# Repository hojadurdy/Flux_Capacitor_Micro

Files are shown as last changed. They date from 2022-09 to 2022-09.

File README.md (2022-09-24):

# Flux Capacitor Micro

### WHAT IS IT?

A tiny (36mm x 29mm) pin badge and keychain PCB version of Flux Capacitor featuring 25 animated LEDs that animate to create the “fluxxing” effect. It’s 100% decorative, it doesn’t actually let you travel through time when worn around the neck.

FLUXXXXING

This tiny Flux Capacitor is controlled by a Microchip ATtiny1616 microcontroller. Thankfully this board has a much lower power requirement than the silkscreen indicates on the back, and skips along, sipping power from the single CR2016/LIR2016 coin cell battery (instead of plutonium or a lightning strike), slipped into the rear mounted coin cell holder. By using PWM (Pulse Width Modulation) pins for 8 channels of 3 paralleled LEDs, different animation patterns are generated for the fluxxxing effect. In settings mode, users are able change between 8 different animation, speed and LED brightness.

### WHAT IS NEW WITH THIS DESIGN?

- Main difference is the new design significantly slimmer due to slim battery holder and changing PCB thickness from 1.6mm to 0.8mm. Older design (V3) had a thickness of 6.15mm, the new design is only 3.4mm thick. 
- Front design has been updated to look like similar to Flux Capacitor Mini design. 
- A much brighter center LED has been added to get a brighter center beam flash, similar to the original Flux Capacitor.
- Instead of just 2 animations, now there are 8 different animations that can be selected in settings.
- Power toggle switch has been replaced with a push button. When pressed device goes in do "Power Down" mode. during "Power Down" mode device only consumes 0.5 uA.

Below you can see the thickness comparison of V3 on the left and V4 on the right.

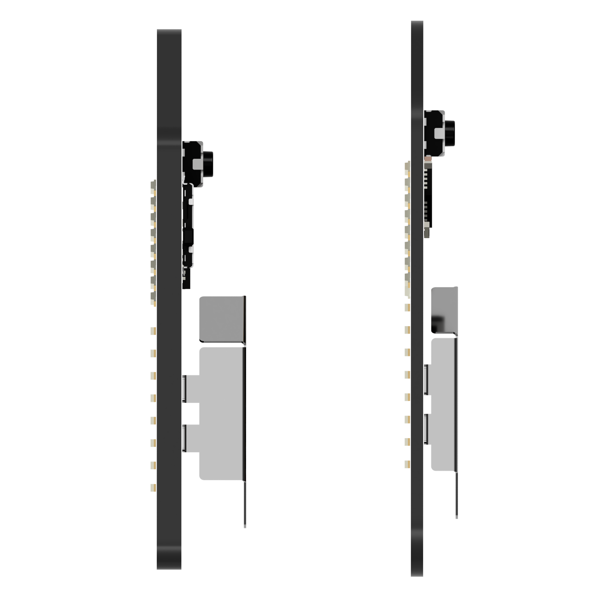
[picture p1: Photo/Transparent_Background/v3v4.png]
V3 vs V4


### HOW LONG WILL THE BATTERY LAST?

CR2016 (Non-Rechargeable) with average of 90 mAh battery capacity.

- 100% LED Brightness :  80 Hours
- 25%  LED Brightness :  128 Hours

LIR2016 (Rechargeable) with average of 20 mAh battery capacity.

- 100% LED Brightness :  18 Hours
- 25%  LED Brightness :  28 Hours

### HOW TO SETUP AND OPERATE

To begin with, turn on the device by pressing power button. In order to enter settings mode just hold the set button for 1 second. If all of the LEDs flashes twice, you are successfully entered settings mode. 

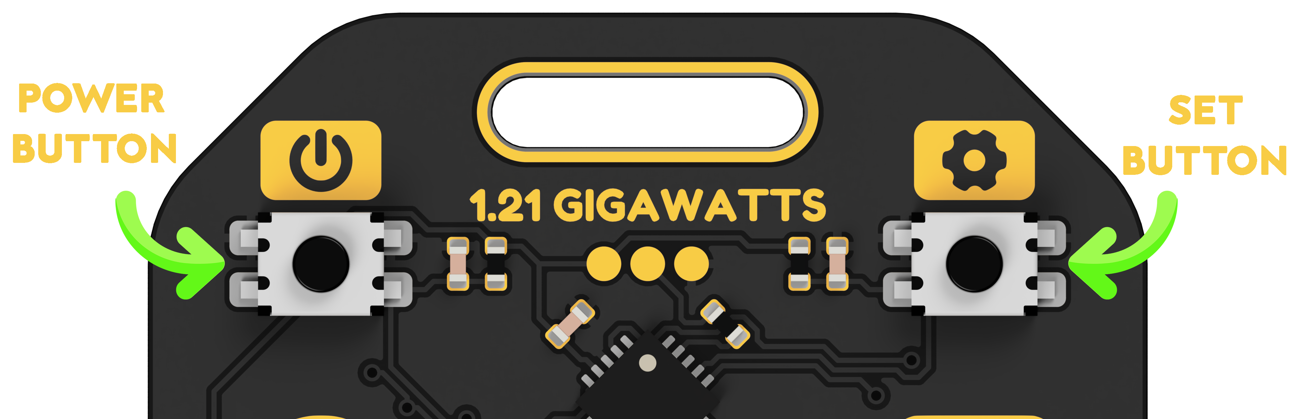
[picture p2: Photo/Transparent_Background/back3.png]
BUTTONS BUTTONS


After the LEDs flash you will see that only single LED remains on. That single LED shows which animation is selected. To change that, just short press the set button and the LED should start shifting from inner to outer LED with each press. After selecting the preferred animation, hold the set button for 1 second to save. LEDs should flash twice to confirm.

Next setting is animation speed. To change the animation speed, just short press the set button to increase the speed. LEDs will turn on from inner to outer to indicate animation speed. At maximum speed all LEDs should be on. Hold the set button for 1 second to save animation speed. LEDs should flash twice to confirm.

Last setting is LED brightness. Same as before to change the brightness just short press the set buttonto increase the brightness. LEDs will turn on from inner to outer to indicate brightness level. At maximum brightness all LEDs should be on. Hold the set button for 1 second to save brightness setting. LEDs should flash twice to confirm and device should exit the setting mode. LEDs should start animating.

**If you short press the button with gear icon during normal operation, device initiates engage mode.
LEDs start to animate faster with much brighter center beam as shown in the video below.**

### P.S.
**Only CR2016 or LIR2016 batteries are compatible. If you prefer to use larger CR2032 or LIR2032 batteries, message me from store page. I will change the battery holder to a larger one. Also batteries are not included due to shipping restrictions.**



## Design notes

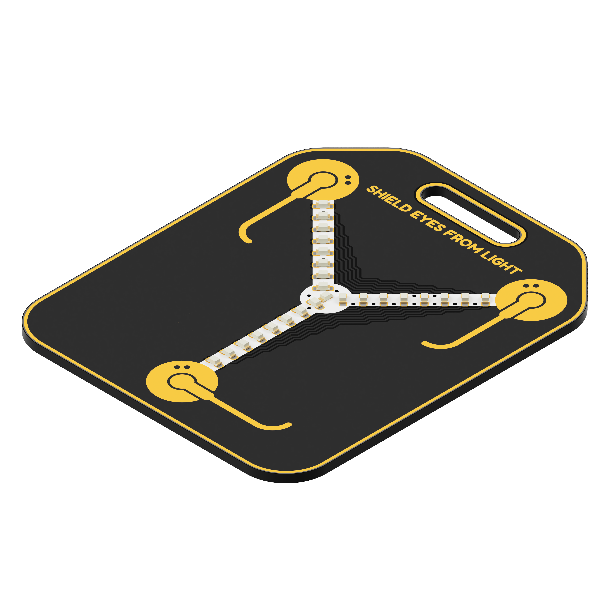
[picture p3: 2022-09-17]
Photo/Transparent_Background/bottom_corner_2.png

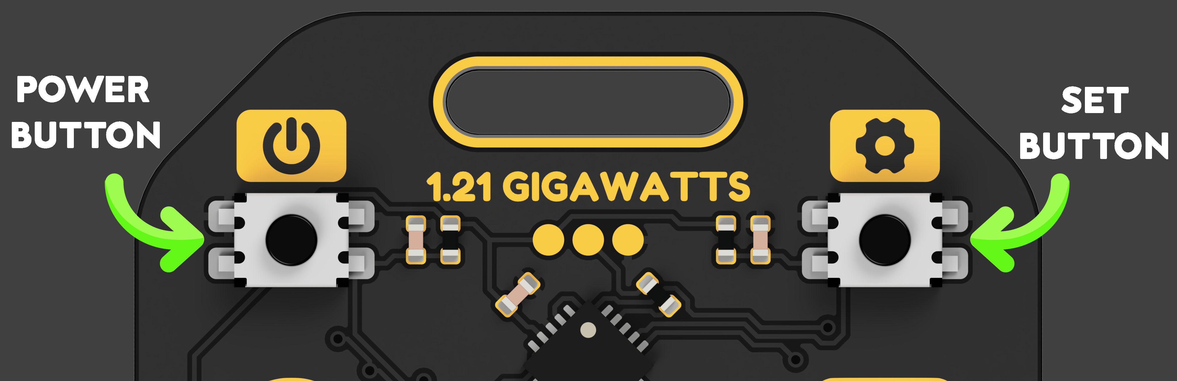
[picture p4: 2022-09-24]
Photo/Transparent_Background/back2.png

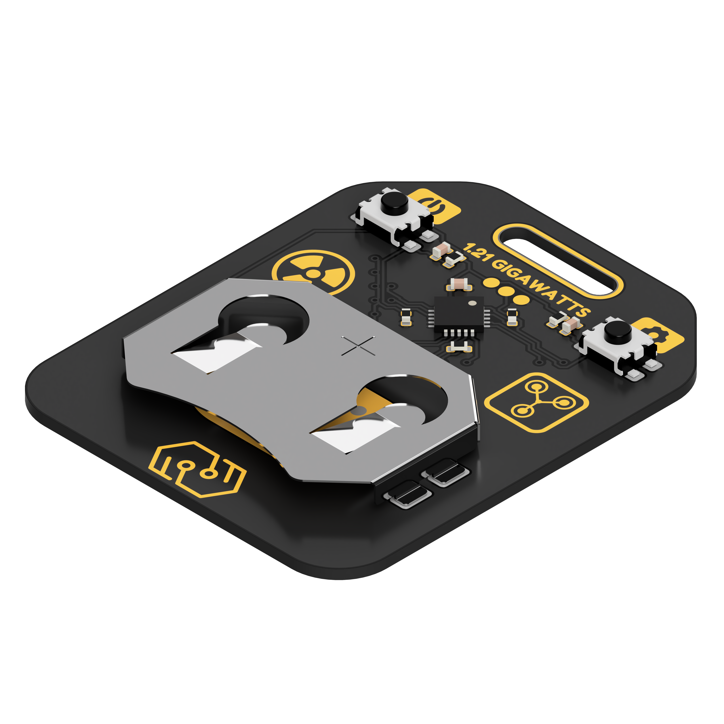
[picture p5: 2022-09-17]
Photo/Transparent_Background/bottom_corner.png

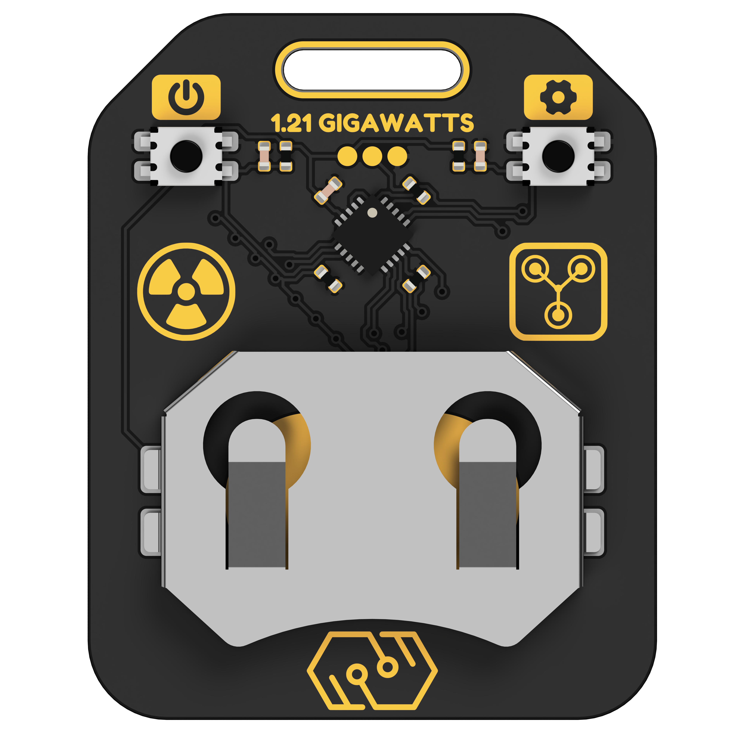
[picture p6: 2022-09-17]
Photo/Transparent_Background/back.png

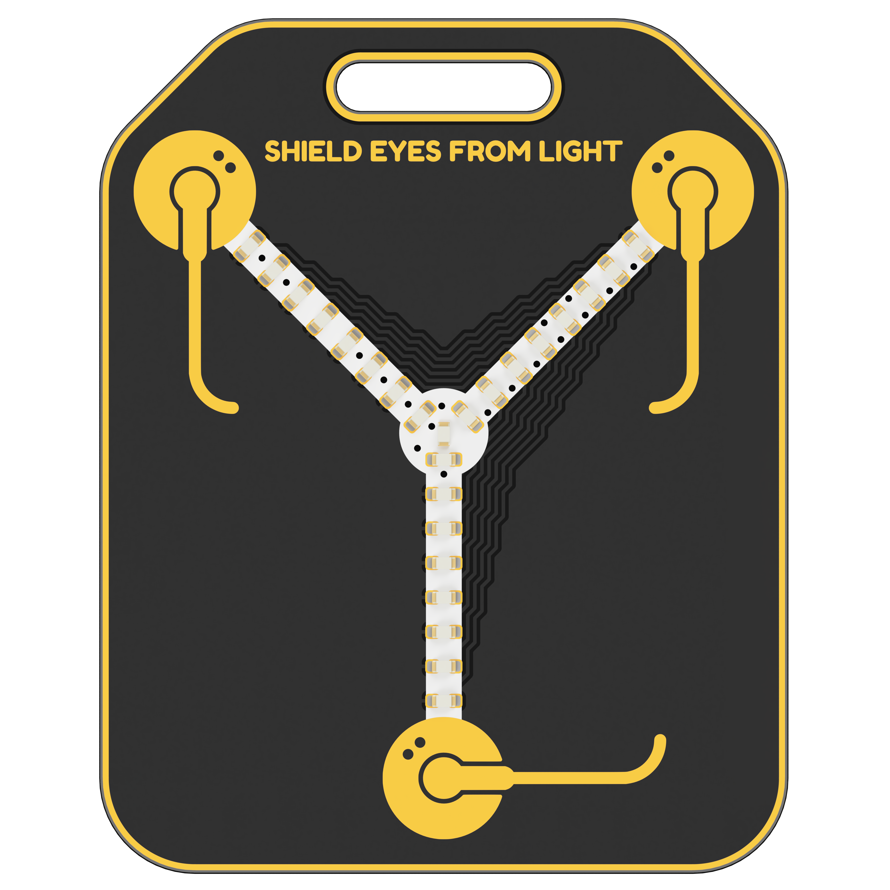
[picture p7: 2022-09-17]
Photo/Transparent_Background/front.png

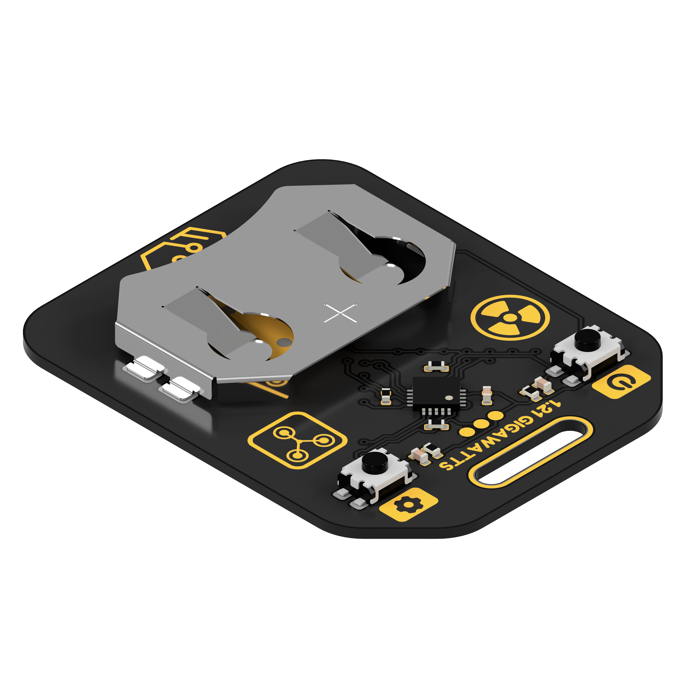
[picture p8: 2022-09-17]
Photo/Transparent_Background/top_corner.png

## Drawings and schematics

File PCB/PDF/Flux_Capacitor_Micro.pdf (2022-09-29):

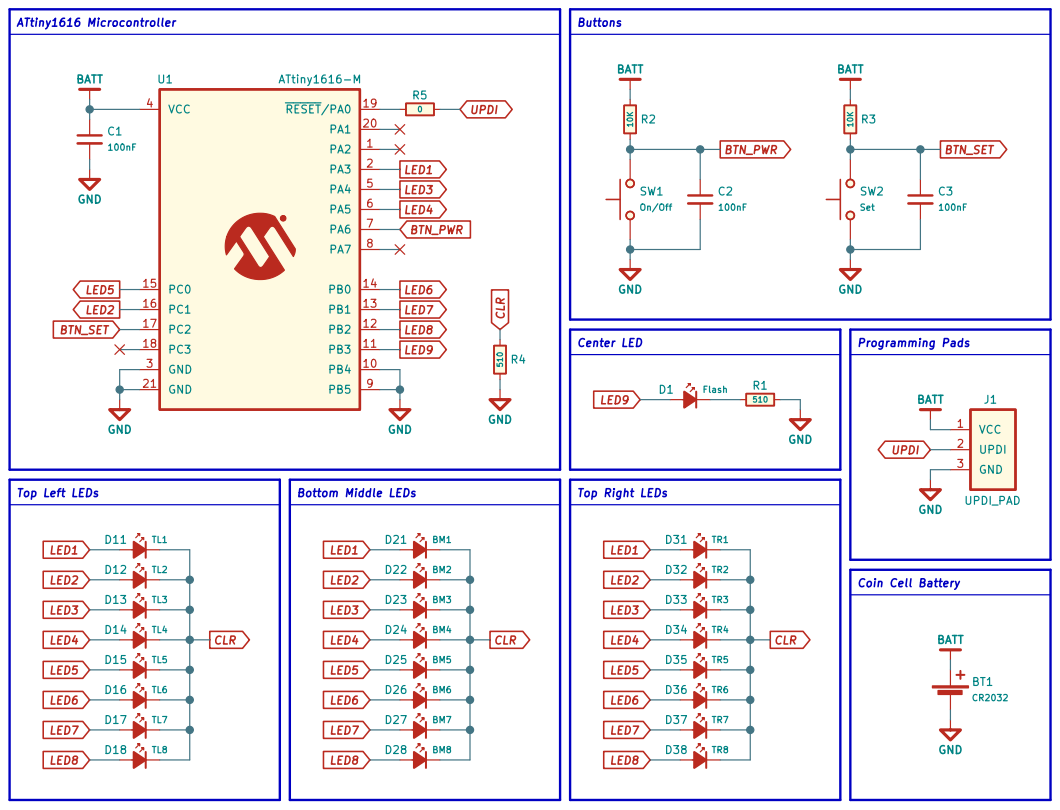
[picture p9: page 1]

Curious Design Labs | Hojadurdy Durdygylyjov

Micro version of Flux Capacitor from the movie Back to the Future

License: CC BY-NC-SA 4.0 Sheet: 1/1

File: Flux_Capacitor_Micro.kicad_sch

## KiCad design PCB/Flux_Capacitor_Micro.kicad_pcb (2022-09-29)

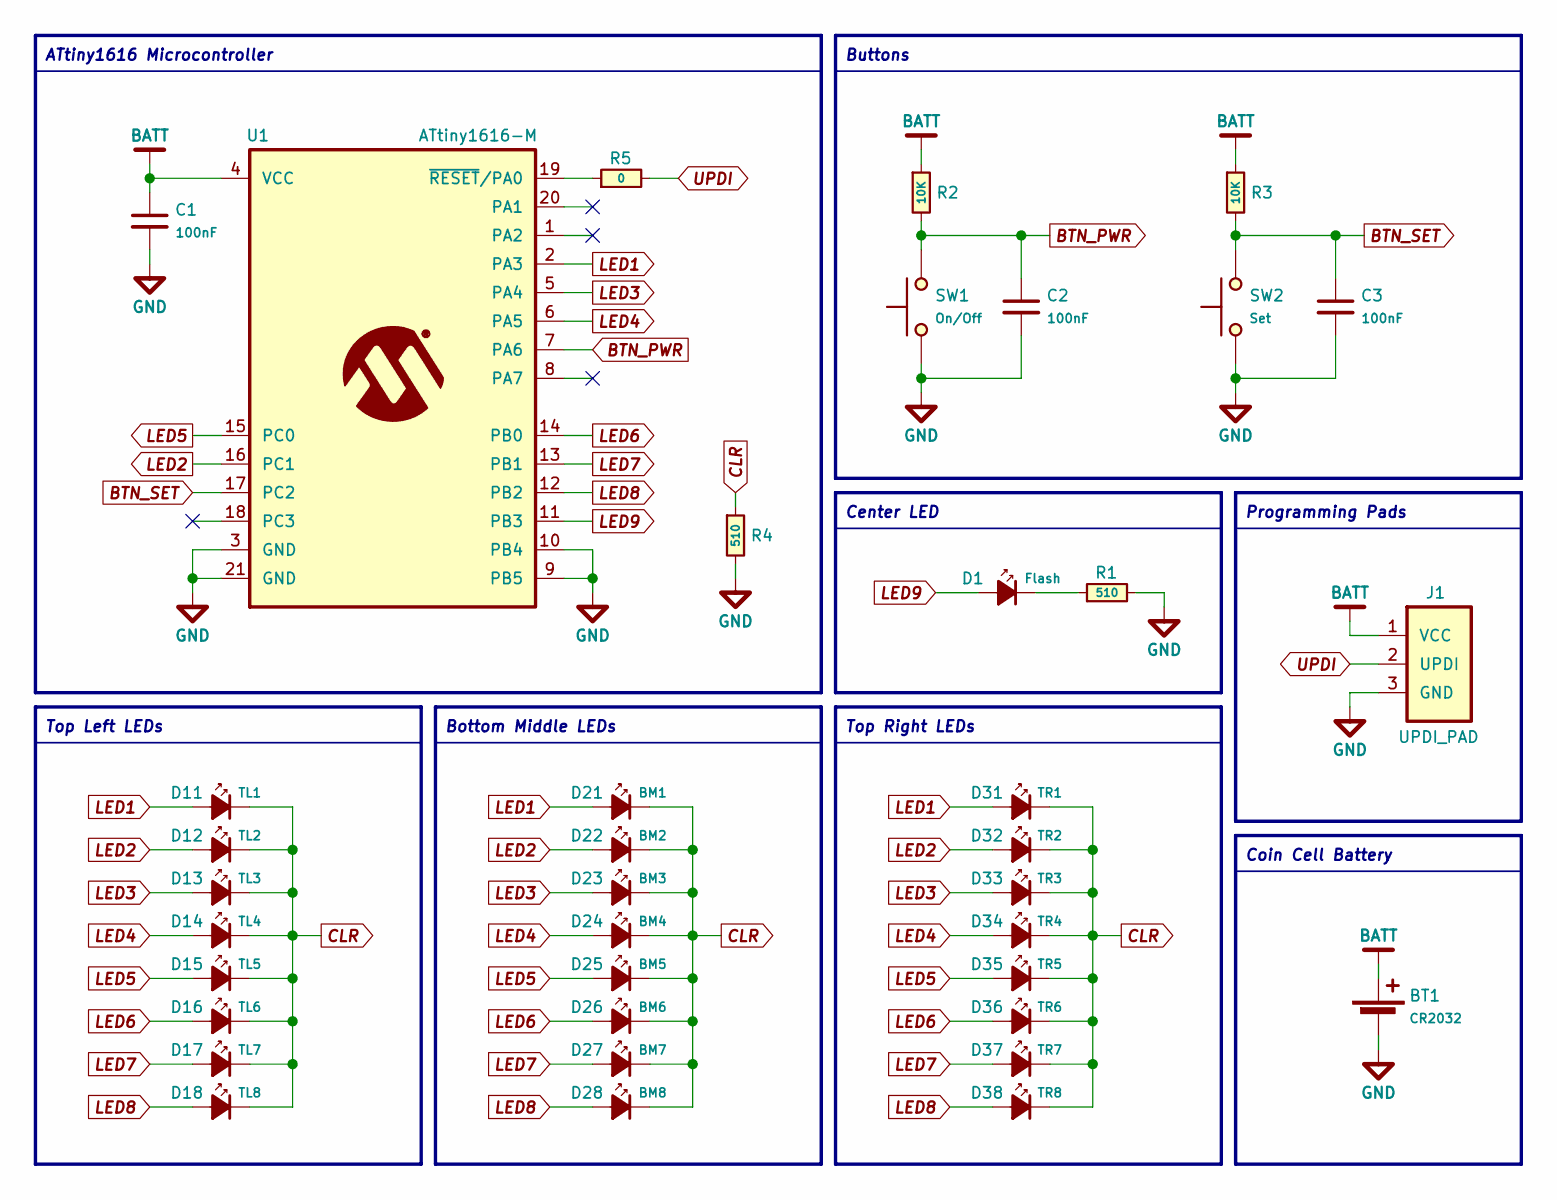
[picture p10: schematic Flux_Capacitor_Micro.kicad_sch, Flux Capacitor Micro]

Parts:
BT1: CR2032; MY-2016-02
C1, C2, C3: 100nF; C_0402_1005Metric
D1: Flash; LED_0402_1005Metric
D11: TL1; LED_0402_1005Metric
D12: TL2; LED_0402_1005Metric
D13: TL3; LED_0402_1005Metric
D14: TL4; LED_0402_1005Metric
D15: TL5; LED_0402_1005Metric
D16: TL6; LED_0402_1005Metric
D17: TL7; LED_0402_1005Metric
D18: TL8; LED_0402_1005Metric
D21: BM1; LED_0402_1005Metric
D22: BM2; LED_0402_1005Metric
D23: BM3; LED_0402_1005Metric
D24: BM4; LED_0402_1005Metric
D25: BM5; LED_0402_1005Metric
D26: BM6; LED_0402_1005Metric
D27: BM7; LED_0402_1005Metric
D28: BM8; LED_0402_1005Metric
D31: TR1; LED_0402_1005Metric
D32: TR2; LED_0402_1005Metric
D33: TR3; LED_0402_1005Metric
D34: TR4; LED_0402_1005Metric
D35: TR5; LED_0402_1005Metric
D36: TR6; LED_0402_1005Metric
D37: TR7; LED_0402_1005Metric
D38: TR8; LED_0402_1005Metric
J1: UPDI_PAD; PogoPad_1x03_P1.27mm
R1, R4: 510; R_0402_1005Metric
R2, R3: 10K; R_0402_1005Metric
R5: 0; R_0402_1005Metric
SW1: On/Off; K2-1809SN-D4DW-06
SW2: Set; K2-1809SN-D4DW-06
U1: ATtiny1616-M; VQFN-20-1EP_3x3mm_P0.4mm_EP1.7x1.7mm

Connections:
BATT: BT1.1 (+), C1.1, J1.1 (VCC), R2.1, R3.1, U1.4 (VCC)
BTN_PWR: C2.1, R2.2, SW1.2, U1.7 (PA6)
BTN_SET: C3.1, R3.2, SW2.2, U1.17 (PC2)
CLR: D11.1 (K), D12.1 (K), D13.1 (K), D14.1 (K), D15.1 (K), D16.1 (K), D17.1 (K), D18.1 (K), D21.1 (K), D22.1 (K), D23.1 (K), D24.1 (K), D25.1 (K), D26.1 (K), D27.1 (K), D28.1 (K), D31.1 (K), D32.1 (K), D33.1 (K), D34.1 (K), D35.1 (K), D36.1 (K), D37.1 (K), D38.1 (K), R4.1
GND: BT1.2 (-), C1.2, C2.2, C3.2, J1.3 (GND), R1.2, R4.2, SW1.1, SW2.1, U1.3 (GND), U1.9 (PB5), U1.10 (PB4), U1.21 (GND)
LED1: D11.2 (A), D21.2 (A), D31.2 (A), U1.2 (PA3)
LED2: D12.2 (A), D22.2 (A), D32.2 (A), U1.16 (PC1)
LED3: D13.2 (A), D23.2 (A), D33.2 (A), U1.5 (PA4)
LED4: D14.2 (A), D24.2 (A), D34.2 (A), U1.6 (PA5)
LED5: D15.2 (A), D25.2 (A), D35.2 (A), U1.15 (PC0)
LED6: D16.2 (A), D26.2 (A), D36.2 (A), U1.14 (PB0)
LED7: D17.2 (A), D27.2 (A), D37.2 (A), U1.13 (PB1)
LED8: D18.2 (A), D28.2 (A), D38.2 (A), U1.12 (PB2)
LED9: D1.2 (A), U1.11 (PB3)
unnamed: D1.1 (K), R1.1
unnamed: R5.1, U1.19 (~RESET/PA0)
UPDI: J1.2 (UPDI), R5.2

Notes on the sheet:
Coin Cell Battery
Center LED
Top Right LEDs
Bottom Middle LEDs
Top Left LEDs
Programming Pads
ATtiny1616 Microcontroller
Buttons

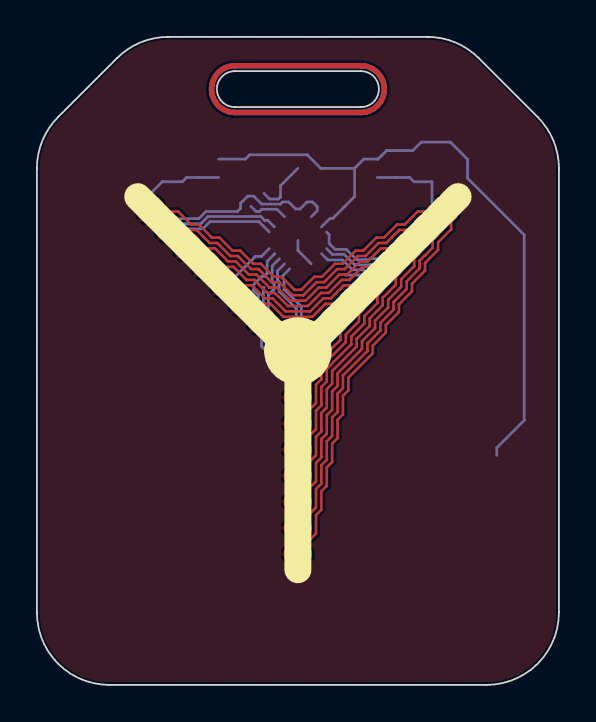
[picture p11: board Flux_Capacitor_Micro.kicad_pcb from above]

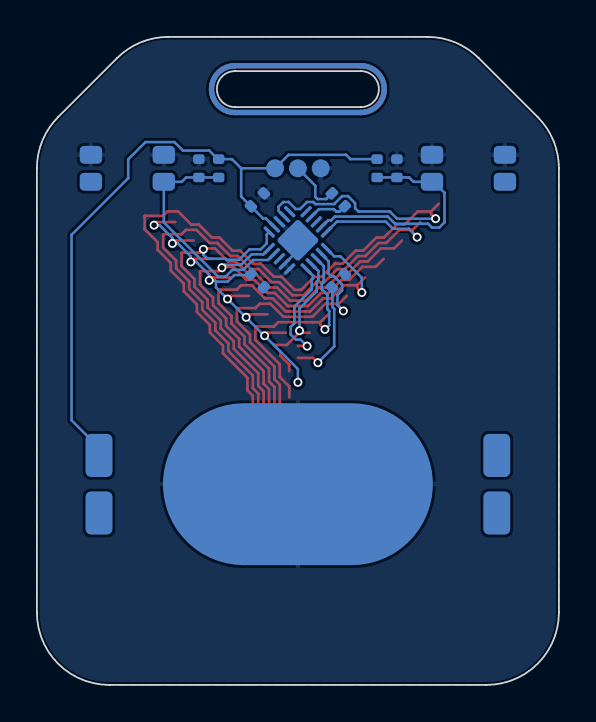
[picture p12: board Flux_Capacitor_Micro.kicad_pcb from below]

Board: 2 copper layers, 29.0 x 36.0 mm, 40 parts (14 on the bottom side), 17 nets.

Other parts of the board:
svg2mod, svg2mod#2: G***; svg2mod

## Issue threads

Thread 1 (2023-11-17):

PCB license is missing

Goury, 2023-11-17:
Since you don't ship to my country, doing it myself is the only option I have.
Please push some license for the KiCad files.

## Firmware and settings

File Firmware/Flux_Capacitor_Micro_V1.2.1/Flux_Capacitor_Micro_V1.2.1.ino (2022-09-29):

/************************************************************************************************
 * Ver:     1.2
 * MCU:     ATtiny1616-M
 * Clock:   1MHz Internal
 * Timer:   Enabled (default timer)
 * Startup: 8ms
 * BOD VL:  1.8V
 * EEPROM:  EEPROM Retained
 * 
 * Uses One Button Library from Matthias Hertel https://github.com/mathertel/OneButton
 * Compiled in Arduino IDE using Spence Konde's megaTinyCore (https://github.com/SpenceKonde/megaTinyCore)
 * 
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
 * THE SOFTWARE IS PROVIDED "AS IS", WITHOUT WARRANTY OF ANY KIND, EXPRESS OR IMPLIED, INCLUDING 
 * BUT NOT LIMITED TO THE WARRANTIES OF MERCHANTABILITY, FITNESS FOR A PARTICULAR PURPOSE AND 
 * NONINFRINGEMENT. IN NO EVENT SHALL THE AUTHORS OR COPYRIGHT HOLDERS BE LIABLE FOR ANY CLAIM, 
 * DAMAGES OR OTHER LIABILITY, WHETHER IN AN ACTION OF CONTRACT, TORT OR OTHERWISE, ARISING FROM, 
 * OUT OF OR IN CONNECTION WITH THE SOFTWARE OR THE USE OR OTHER DEALINGS IN THE SOFTWARE.
 ************************************************************************************************/
 
#include <EEPROM.h>
#include <OneButton.h>
#include <avr/sleep.h>

//PIN DEFINITIONS

#define setButton     12
#define powerButton   2

OneButton button(setButton, true);

const int leds[9]={16, 11, 0, 1, 10, 9, 8, 7, 6};

//VARIABLES
unsigned long pressStartTime;
byte engageSequenceBegin = 0;


byte startupMode;             //   0,   1,   2,   3
byte settingsMode;            //   0,   1,   2

byte animationSequence;       //   1,   2,   3,   4,   5,   6,   7,   8
byte animationSpeed;          // 100,  90,  80,  70,  60,  50,  40,  30
byte ledBrightness;           //  31,  63,  95, 127, 159, 191, 223, 255 

//SETTINGS EEPROM ADDRESS
#define startupModeAddr         1
#define settingsModeAddr        2
#define animationSequenceAddr   11     
#define animationSpeedAddr      12   
#define ledBrightnessAddr       13    

//---------------------------------------------------------------------------------------------------------//

void startupSequence() {
    startupMode = EEPROM.read(startupModeAddr);
    settingsMode = EEPROM.read(settingsModeAddr);
    animationSequence = EEPROM.read(animationSequenceAddr);
    animationSpeed = EEPROM.read(animationSpeedAddr);
    ledBrightness = EEPROM.read(ledBrightnessAddr);
}

void devicePowerDown() {
    for(int b=0;b<=8;b++) {
        digitalWrite(leds[b], 0);
    }
    ADC0.CTRLA &= ~ADC_ENABLE_bm;
    sleep_cpu();
}

void devicePowerUp() {
    sleep_disable();
    EEPROM.write(startupModeAddr, 1);
}

void powerOnOff() {
    if(startupMode != 2) {
        EEPROM.write(startupModeAddr, 2);
    }
    else if(startupMode == 2) {
        EEPROM.write(startupModeAddr, 3);
    } 
} 

void checkTicks() {
    button.tick();
}

void flashLEDs(byte c) {
    for(int i=0;i<c;i++) {
        for(int b=0;b<=7;b++) {
            digitalWrite(leds[b], 0);
        }
        digitalWrite(leds[8], 0);
        delay(120);
        for(int b=0;b<=7;b++) {
            digitalWrite(leds[b], 1);
        }
        delay(60);
    }
    for(int b=0;b<=7;b++) {
        digitalWrite(leds[b], 0);
    }
}

// this function will be called when the button was held down for 1 second or more.
void pressStart() {
    pressStartTime = millis() - 1000; // as set in setPressTicks()
} 

// this function will be called when the button was released after a long hold.
void deviceSettingsSelect() {
    if(startupMode == 0 && settingsMode == 0) {
        EEPROM.write(settingsModeAddr, 1);
        flashLEDs(2);
    }
    else if(startupMode == 0 && settingsMode == 1) {
        EEPROM.write(settingsModeAddr, 2);
        flashLEDs(2);
    }
    else if(startupMode == 0 && settingsMode == 2) {
        EEPROM.write(startupModeAddr, 1);
        flashLEDs(2);
    }
    else if(startupMode == 1) {
        EEPROM.write(startupModeAddr, 0);
        EEPROM.write(settingsModeAddr, 0);
        flashLEDs(2);
    }
}

void singleClick() {
    if(startupMode == 0 && settingsMode == 0) {
        if(animationSequence == 8) {
            EEPROM.write(animationSequenceAddr, 7);
        }
        else if(animationSequence == 7) {
            EEPROM.write(animationSequenceAddr, 6);
        }
        else if(animationSequence == 6) {
            EEPROM.write(animationSequenceAddr, 5);
        }
        else if(animationSequence == 5) {
            EEPROM.write(animationSequenceAddr, 4);
        }
        else if(animationSequence == 4) {
            EEPROM.write(animationSequenceAddr, 3);
        }
        else if(animationSequence == 3) {
            EEPROM.write(animationSequenceAddr, 2);
        }
        else if(animationSequence == 2) {
            EEPROM.write(animationSequenceAddr, 1);
        }
        else if(animationSequence == 1) {
            EEPROM.write(animationSequenceAddr, 8);
        }
    }
    else if(startupMode == 0 && settingsMode == 1) {
        if(animationSpeed == 100) {
            EEPROM.write(animationSpeedAddr, 90);
        }
        else if(animationSpeed == 90) {
            EEPROM.write(animationSpeedAddr, 80);
        }
        else if(animationSpeed == 80) {
            EEPROM.write(animationSpeedAddr, 70);
        }
        else if(animationSpeed == 70) {
            EEPROM.write(animationSpeedAddr, 60);
        }
        else if(animationSpeed == 60) {
            EEPROM.write(animationSpeedAddr, 50);
        }
        else if(animationSpeed == 50) {
            EEPROM.write(animationSpeedAddr, 40);
        }
        else if(animationSpeed == 40) {
            EEPROM.write(animationSpeedAddr, 30);
        }
        else if(animationSpeed == 30) {
            EEPROM.write(animationSpeedAddr, 100);
        }
    }
    else if(startupMode == 0 && settingsMode == 2) {
        if(ledBrightness == 31) {
            EEPROM.write(ledBrightnessAddr, 63);
        }
        else if(ledBrightness == 63) {
            EEPROM.write(ledBrightnessAddr, 95);
        }
        else if(ledBrightness == 95) {
            EEPROM.write(ledBrightnessAddr, 127);
        }
        else if(ledBrightness == 127) {
            EEPROM.write(ledBrightnessAddr, 159);
        }
        else if(ledBrightness == 159) {
            EEPROM.write(ledBrightnessAddr, 191);
        }
        else if(ledBrightness == 191) {
            EEPROM.write(ledBrightnessAddr, 223);
        }
        else if(ledBrightness == 223) {
            EEPROM.write(ledBrightnessAddr, 255);
        }
        else if(ledBrightness == 255) {
            EEPROM.write(ledBrightnessAddr, 31);
        }
    }
    else if (startupMode == 1) {
        engageSequenceBegin = 1;
    }
}

void showAnimationSequenceSetting() {
    if(animationSequence == 1) {
      digitalWrite(leds[0], 1);
      digitalWrite(leds[1], 0);
      digitalWrite(leds[2], 0);
      digitalWrite(leds[3], 0);
      digitalWrite(leds[4], 0);
      digitalWrite(leds[5], 0);
      digitalWrite(leds[6], 0);
      digitalWrite(leds[7], 0);
    }
    else if(animationSequence == 2) {
        digitalWrite(leds[0], 0);
        digitalWrite(leds[1], 1);
        digitalWrite(leds[2], 0);
        digitalWrite(leds[3], 0);
        digitalWrite(leds[4], 0);
        digitalWrite(leds[5], 0);
        digitalWrite(leds[6], 0);
        digitalWrite(leds[7], 0);
    }
    else if(animationSequence == 3) {
        digitalWrite(leds[0], 0);
        digitalWrite(leds[1], 0);
        digitalWrite(leds[2], 1);
        digitalWrite(leds[3], 0);
        digitalWrite(leds[4], 0);
        digitalWrite(leds[5], 0);
        digitalWrite(leds[6], 0);
        digitalWrite(leds[7], 0);
    }
    else if(animationSequence == 4) {
        digitalWrite(leds[0], 0);
        digitalWrite(leds[1], 0);
        digitalWrite(leds[2], 0);
        digitalWrite(leds[3], 1);
        digitalWrite(leds[4], 0);
        digitalWrite(leds[5], 0);
        digitalWrite(leds[6], 0);
        digitalWrite(leds[7], 0);
    }
    else if(animationSequence == 5) {
        digitalWrite(leds[0], 0);
        digitalWrite(leds[1], 0);
        digitalWrite(leds[2], 0);
        digitalWrite(leds[3], 0);
        digitalWrite(leds[4], 1);
        digitalWrite(leds[5], 0);
        digitalWrite(leds[6], 0);
        digitalWrite(leds[7], 0);
    }
    else if(animationSequence == 6) {
        digitalWrite(leds[0], 0);
        digitalWrite(leds[1], 0);
        digitalWrite(leds[2], 0);
        digitalWrite(leds[3], 0);
        digitalWrite(leds[4], 0);
        digitalWrite(leds[5], 1);
        digitalWrite(leds[6], 0);
        digitalWrite(leds[7], 0);
    }
    else if(animationSequence == 7) {
        digitalWrite(leds[0], 0);
        digitalWrite(leds[1], 0);
        digitalWrite(leds[2], 0);
        digitalWrite(leds[3], 0);
        digitalWrite(leds[4], 0);
        digitalWrite(leds[5], 0);
        digitalWrite(leds[6], 1);
        digitalWrite(leds[7], 0);
    }
    else if(animationSequence == 8) {
        digitalWrite(leds[0], 0);
        digitalWrite(leds[1], 0);
        digitalWrite(leds[2], 0);
        digitalWrite(leds[3], 0);
        digitalWrite(leds[4], 0);
        digitalWrite(leds[5], 0);
        digitalWrite(leds[6], 0);
        digitalWrite(leds[7], 1);
    }
}

void showAnimationSpeedSetting() {
    if(animationSpeed == 30) {
        digitalWrite(leds[0], 1);
        digitalWrite(leds[1], 1);
        digitalWrite(leds[2], 1);
        digitalWrite(leds[3], 1);
        digitalWrite(leds[4], 1);
        digitalWrite(leds[5], 1);
        digitalWrite(leds[6], 1);
        digitalWrite(leds[7], 1);
    }
    else if(animationSpeed == 40) {
        digitalWrite(leds[0], 0);
        digitalWrite(leds[1], 1);
        digitalWrite(leds[2], 1);
        digitalWrite(leds[3], 1);
        digitalWrite(leds[4], 1);
        digitalWrite(leds[5], 1);
        digitalWrite(leds[6], 1);
        digitalWrite(leds[7], 1);
    }
    else if(animationSpeed == 50) {
        digitalWrite(leds[0], 0);
        digitalWrite(leds[1], 0);
        digitalWrite(leds[2], 1);
        digitalWrite(leds[3], 1);
        digitalWrite(leds[4], 1);
        digitalWrite(leds[5], 1);
        digitalWrite(leds[6], 1);
        digitalWrite(leds[7], 1);
    }
    else if(animationSpeed == 60) {
        digitalWrite(leds[0], 0);
        digitalWrite(leds[1], 0);
        digitalWrite(leds[2], 0);
        digitalWrite(leds[3], 1);
        digitalWrite(leds[4], 1);
        digitalWrite(leds[5], 1);
        digitalWrite(leds[6], 1);
        digitalWrite(leds[7], 1);
    }
    else if(animationSpeed == 70) {
        digitalWrite(leds[0], 0);
        digitalWrite(leds[1], 0);
        digitalWrite(leds[2], 0);
        digitalWrite(leds[3], 0);
        digitalWrite(leds[4], 1);
        digitalWrite(leds[5], 1);
        digitalWrite(leds[6], 1);
        digitalWrite(leds[7], 1);
    }
    else if(animationSpeed == 80) {
        digitalWrite(leds[0], 0);
        digitalWrite(leds[1], 0);
        digitalWrite(leds[2], 0);
        digitalWrite(leds[3], 0);
        digitalWrite(leds[4], 0);
        digitalWrite(leds[5], 1);
        digitalWrite(leds[6], 1);
        digitalWrite(leds[7], 1);
    }
    else if(animationSpeed == 90) {
        digitalWrite(leds[0], 0);
        digitalWrite(leds[1], 0);
        digitalWrite(leds[2], 0);
        digitalWrite(leds[3], 0);
        digitalWrite(leds[4], 0);
        digitalWrite(leds[5], 0);
        digitalWrite(leds[6], 1);
        digitalWrite(leds[7], 1);
    }
    else if(animationSpeed == 100) {
        digitalWrite(leds[0], 0);
        digitalWrite(leds[1], 0);
        digitalWrite(leds[2], 0);
        digitalWrite(leds[3], 0);
        digitalWrite(leds[4], 0);
        digitalWrite(leds[5], 0);
        digitalWrite(leds[6], 0);
        digitalWrite(leds[7], 1);
    }
}

void showLEDBrightnessSetting() {
    if(ledBrightness == 255) {
        digitalWrite(leds[0], 1);
        digitalWrite(leds[1], 1);
        digitalWrite(leds[2], 1);
        digitalWrite(leds[3], 1);
        digitalWrite(leds[4], 1);
        digitalWrite(leds[5], 1);
        digitalWrite(leds[6], 1);
        digitalWrite(leds[7], 1);
    }
    else if(ledBrightness == 223) {
        digitalWrite(leds[0], 0);
        digitalWrite(leds[1], 1);
        digitalWrite(leds[2], 1);
        digitalWrite(leds[3], 1);
        digitalWrite(leds[4], 1);
        digitalWrite(leds[5], 1);
        digitalWrite(leds[6], 1);
        digitalWrite(leds[7], 1);
    }
    else if(ledBrightness == 191) {
        digitalWrite(leds[0], 0);
        digitalWrite(leds[1], 0);
        digitalWrite(leds[2], 1);
        digitalWrite(leds[3], 1);
        digitalWrite(leds[4], 1);
        digitalWrite(leds[5], 1);
        digitalWrite(leds[6], 1);
        digitalWrite(leds[7], 1);
    }
    else if(ledBrightness == 159) {
        digitalWrite(leds[0], 0);
        digitalWrite(leds[1], 0);
        digitalWrite(leds[2], 0);
        digitalWrite(leds[3], 1);
        digitalWrite(leds[4], 1);
        digitalWrite(leds[5], 1);
        digitalWrite(leds[6], 1);
        digitalWrite(leds[7], 1);
    }
    else if(ledBrightness == 127) {
        digitalWrite(leds[0], 0);
        digitalWrite(leds[1], 0);
        digitalWrite(leds[2], 0);
        digitalWrite(leds[3], 0);
        digitalWrite(leds[4], 1);
        digitalWrite(leds[5], 1);
        digitalWrite(leds[6], 1);
        digitalWrite(leds[7], 1);
    }
    else if(ledBrightness == 95) {
        digitalWrite(leds[0], 0);
        digitalWrite(leds[1], 0);
        digitalWrite(leds[2], 0);
        digitalWrite(leds[3], 0);
        digitalWrite(leds[4], 0);
        digitalWrite(leds[5], 1);
        digitalWrite(leds[6], 1);
        digitalWrite(leds[7], 1);
    }
    else if(ledBrightness == 63) {
        digitalWrite(leds[0], 0);
        digitalWrite(leds[1], 0);
        digitalWrite(leds[2], 0);
        digitalWrite(leds[3], 0);
        digitalWrite(leds[4], 0);
        digitalWrite(leds[5], 0);
        digitalWrite(leds[6], 1);
        digitalWrite(leds[7], 1);
    }
    else if(ledBrightness == 31) {
        digitalWrite(leds[0], 0);
        digitalWrite(leds[1], 0);
        digitalWrite(leds[2], 0);
        digitalWrite(leds[3], 0);
        digitalWrite(leds[4], 0);
        digitalWrite(leds[5], 0);
        digitalWrite(leds[6], 0);
        digitalWrite(leds[7], 1);
    }
}

void deviceSettings() {
    switch(settingsMode) {
        case 0:
            showAnimationSequenceSetting();
        break;

        case 1:
            showAnimationSpeedSetting();
        break;

        case 2:
            showLEDBrightnessSetting();
        break;
    }
}

void deviceRun() {
    if(engageSequenceBegin == 1) {
        engageSequence();
        engageSequenceBegin = 0;
    }
    else if(engageSequenceBegin == 0) {
        if(animationSequence == 1) {
            animationSequence1();
        }
        else if(animationSequence == 2) {
            animationSequence2();
        }
        else if(animationSequence == 3) {
            animationSequence3();
        } 
        else if(animationSequence == 4) {
            animationSequence4();
        } 
        else if(animationSequence == 5) {
            animationSequence5();
        } 
        else if(animationSequence == 6) {
            animationSequence6();
        } 
        else if(animationSequence == 7) {
            animationSequence7();
        } 
        else if(animationSequence == 8) {
            animationSequence8();
        }
    }
}

void animationSequence1() {
    float brightnessScaleVal = ledBrightness/255.00;
    analogWrite(leds[0], 31*brightnessScaleVal);
    analogWrite(leds[5], 191*brightnessScaleVal);
    analogWrite(leds[6], 223*brightnessScaleVal);
    delay(animationSpeed); 
    analogWrite(leds[0], 31*brightnessScaleVal);
    analogWrite(leds[1], 63*brightnessScaleVal);
    analogWrite(leds[6], 223*brightnessScaleVal);
    analogWrite(leds[7], 255*brightnessScaleVal);
    analogWrite(leds[5], 0);
    delay(animationSpeed);
    analogWrite(leds[1], 63*brightnessScaleVal);
    analogWrite(leds[2], 95*brightnessScaleVal);
    analogWrite(leds[7], 255*brightnessScaleVal);
    analogWrite(leds[0], 0);
    analogWrite(leds[6], 0);
    delay(animationSpeed);
    analogWrite(leds[2], 95*brightnessScaleVal);
    analogWrite(leds[3], 127*brightnessScaleVal);
    analogWrite(leds[1], 0);
    analogWrite(leds[7], 0);
    delay(animationSpeed);
    analogWrite(leds[3], 127*brightnessScaleVal);
    analogWrite(leds[4], 159*brightnessScaleVal);
    analogWrite(leds[2], 0);
    delay(animationSpeed);
    analogWrite(leds[4], 159*brightnessScaleVal);
    analogWrite(leds[5], 191*brightnessScaleVal);
    analogWrite(leds[3], 0);
    delay(animationSpeed);
    analogWrite(leds[4], 0);
}

void animationSequence2() {
    float brightnessScaleVal = ledBrightness/255.00;
    analogWrite(leds[0], 10*brightnessScaleVal);
    delay(animationSpeed); 
    analogWrite(leds[1], 30*brightnessScaleVal);
    delay(animationSpeed); 
    analogWrite(leds[2], 60*brightnessScaleVal);
    delay(animationSpeed);
    analogWrite(leds[3], 100*brightnessScaleVal);
    delay(animationSpeed);
    analogWrite(leds[4], 150*brightnessScaleVal);
    delay(animationSpeed);
    analogWrite(leds[0], 0);
    analogWrite(leds[1], 10*brightnessScaleVal);
    analogWrite(leds[2], 30*brightnessScaleVal);
    analogWrite(leds[3], 60*brightnessScaleVal);
    analogWrite(leds[4], 100*brightnessScaleVal);
    analogWrite(leds[5], 180*brightnessScaleVal);
    delay(animationSpeed);
    analogWrite(leds[1], 0);
    analogWrite(leds[2], 10*brightnessScaleVal);
    analogWrite(leds[3], 30*brightnessScaleVal);
    analogWrite(leds[4], 70*brightnessScaleVal);
    analogWrite(leds[5], 130*brightnessScaleVal);
    analogWrite(leds[6], 200*brightnessScaleVal);
    delay(animationSpeed);
    analogWrite(leds[2], 0);
    analogWrite(leds[3], 20*brightnessScaleVal);
    analogWrite(leds[4], 80*brightnessScaleVal);
    analogWrite(leds[5], 150*brightnessScaleVal);
    analogWrite(leds[6], 180*brightnessScaleVal);
    analogWrite(leds[7], 255*brightnessScaleVal);
    delay(animationSpeed);
    analogWrite(leds[3], 0);
    delay(animationSpeed);
    analogWrite(leds[4], 0);
    delay(animationSpeed);
    analogWrite(leds[5], 0);
    delay(animationSpeed);
    analogWrite(leds[6], 0);
    delay(animationSpeed);
    analogWrite(leds[7], 0);
}

void animationSequence3() {
    for(int i=0;i<=7;i++) {
        analogWrite(leds[i-1], 0);
        analogWrite(leds[i], ledBrightness);
        delay(animationSpeed);
    }
    for(int i=7;i>=0;i--) {
        analogWrite(leds[i+1], 0);
        analogWrite(leds[i], ledBrightness);
        delay(animationSpeed);
    }
}

void animationSequence4() {
    analogWrite(leds[3], ledBrightness);
    analogWrite(leds[4], ledBrightness);
    delay(animationSpeed*2.5);
    analogWrite(leds[3], 0);
    analogWrite(leds[4], 0);
    analogWrite(leds[2], ledBrightness*0.6);
    analogWrite(leds[5], ledBrightness*0.6);
    delay(animationSpeed*1.6);
    analogWrite(leds[2], 0);
    analogWrite(leds[5], 0);
    analogWrite(leds[1], ledBrightness*0.3);
    analogWrite(leds[6], ledBrightness*0.3);
    delay(animationSpeed*1.9);
    analogWrite(leds[1], 0);
    analogWrite(leds[6], 0);
    analogWrite(leds[0], ledBrightness*0.1);
    analogWrite(leds[7], ledBrightness*0.1);
    delay(animationSpeed*2.2);
    analogWrite(leds[0], 0);
    analogWrite(leds[7], 0);
    delay(animationSpeed*2.5);
}

void animationSequence5() {
    analogWrite(leds[2], 0);
    analogWrite(leds[5], 0);
    analogWrite(leds[3], ledBrightness);
    analogWrite(leds[4], ledBrightness);
    delay(animationSpeed*2.5);
    analogWrite(leds[3], 0);
    analogWrite(leds[4], 0);
    analogWrite(leds[2], ledBrightness*0.6);
    analogWrite(leds[5], ledBrightness*0.6);
    delay(animationSpeed*1.6);
    analogWrite(leds[2], 0);
    analogWrite(leds[5], 0);
    analogWrite(leds[1], ledBrightness*0.3);
    analogWrite(leds[6], ledBrightness*0.3);
    delay(animationSpeed*1.9);
    analogWrite(leds[1], 0);
    analogWrite(leds[6], 0);
    analogWrite(leds[0], ledBrightness*0.1);
    analogWrite(leds[7], ledBrightness*0.1);
    delay(animationSpeed*2.2);
    analogWrite(leds[0], 0);
    analogWrite(leds[7], 0);
    analogWrite(leds[1], ledBrightness*0.3);
    analogWrite(leds[6], ledBrightness*0.3);
    delay(animationSpeed*1.9);
    analogWrite(leds[1], 0);
    analogWrite(leds[6], 0);
    analogWrite(leds[2], ledBrightness*0.6);
    analogWrite(leds[5], ledBrightness*0.6);
    delay(animationSpeed*1.6);
}

void animationSequence6() {
    morseCode_S();  
    morseCode_O();
    morseCode_S();
    delay(600);
}

void animationSequence7() {
    for(int i=0;i<8;i++) {
        analogWrite(leds[i-1], 0);
        analogWrite(leds[i], ledBrightness);
        delay(animationSpeed/4);
    }
    digitalWrite(leds[7], 0);
    delay(60);
    for(int i=0;i<8;i++) {
        analogWrite(leds[i-1], 0);
        analogWrite(leds[i], ledBrightness);
        delay(animationSpeed/4);
    }
    digitalWrite(leds[7], 0);
    delay(500);
}

void animationSequence8() {
    for(int i=0;i<8;i++) {
        analogWrite(leds[i-1], 0);
        analogWrite(leds[i], ledBrightness);
        delay(animationSpeed);
    }
    digitalWrite(leds[7], 0);
}
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
void loop() {
    button.tick();
    startupSequence();          
    switch(startupMode) {
        case 0:
            deviceSettings();
        break;

        case 1:
            deviceRun();
        break;

        case 2:
            devicePowerDown();
        break;

        case 3:
            devicePowerUp();
        break;
    }
}

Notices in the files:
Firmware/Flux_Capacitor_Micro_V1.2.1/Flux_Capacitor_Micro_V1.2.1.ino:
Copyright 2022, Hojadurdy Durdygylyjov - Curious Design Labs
